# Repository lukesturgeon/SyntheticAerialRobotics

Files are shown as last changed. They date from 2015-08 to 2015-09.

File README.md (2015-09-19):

# SyntheticAerialRobotics #

Working repository for control software and Arduino code to choreograph a robotic performance. Using 4 stepper motors, drivers and software. This repository is started during a two month residency at [Laboratory](http://laboratoryspokane.com) Spokane and is a development of an original project [Choreographed Synthetic Temperaments in Aerial Robotics](http://lukesturgeon.co.uk/Choreographed-Synthetic-Temperaments-in-Aerial-Robotics).

---

## Arduino ##

#### AccelStepper_x4
A working sketch that allows serial communication to control and calibrate four stepper motors simultaniously. At it's core is the Calibrated_AccelStepper class which extends the awesome [AccelStepper library](http://www.airspayce.com/mikem/arduino/AccelStepper/) to include a calibration method using a limit switch to wind in and then unwind the cables.

##### Commands
- 1,2,3,4 : four long int to move each motor to the new length in MM
- s : sleep
- w : wake
- u : unlock
- l : lock
- ccw0 : 1 step counterclockwise for motor 0
- cw2 : 1 step clockwise for motor 2
- z1 : set current position to zero for motor 1
- c3 : start calibration process for motor 3
- ms : set max speed
- ma : set max acceleration
- ?l : get locked status
- ?s : get sleep status
- ?c : et calibration status (all four motors)
- ?mm : get length in MM (all four motors)

---

## Processing ##

#### SyntheticAerialRoboticsInterface
A working sketch to visualise and measure the position of the actor in 3D space. Using real-world measurements in CM to construct the box, all values afterwards will work at that scale.

#### single_stepper_controller
A working sketch that includes all basic interface elements necessary to interact with a single motor.

---

## Resources ##
- Datasheets for variable electronic components
- quadstepper.fzz : The circuit diagram and components created in Fritzing.
- powersupply.pdf : The power supply used for the installation 12V 5A
- motor-unit.ai : The illustrator file used to fabricate the acrylic sheets to assemble the four motor units. This file is to scale but some measurements are imprecise. File reflects the changes made manually to the current working acrylic sheets.
- installation-setup.ai : floorplan and dimensions for public installation at Laboratory Residency in Spokane, US.

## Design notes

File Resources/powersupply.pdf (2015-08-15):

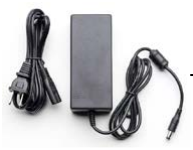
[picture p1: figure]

12V 5A switching power supply
—
It can supply 12V DC up to 5 Amps, running from 110V or 220V power (https://www.adafruit.com/products/352)

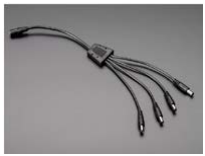
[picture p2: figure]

4-Way 2.1mm DC Barrel Jack Splitter
—
(https://www.adafruit.com/products/1352)

2.1mm female/mail barrel jack extension cable 1.5m —
The heavy 22 AWG wires can handle up to 5A. (https://www.adafruit.com/products/327)

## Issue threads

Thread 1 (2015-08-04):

unsynced position between oF and arduino

lukesturgeon, 2015-08-04:
this causes the motors to repostion and tare things apart.

currentposition in OF needs to be live and pulled from arduino directly.

lukesturgeon, 2015-08-13:
this has been fixed with a capacitor between RESET pin and GND. the arduino will not reset when multiple serial connections are made. so you can repeatedly connect without reseting the board. then query the board to get the current positions etc.

Closed 2015-08-13.

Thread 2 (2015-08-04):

tracking people close/far through glass windows

lukesturgeon, 2015-08-04:

lukesturgeon, 2015-08-04:
people tracking could be done with
– facetracking (faces)
– bodtracking (human)
– object tracking (red ball)
– Kinect?

https://github.com/hirotakaster/ofxOpenNI2

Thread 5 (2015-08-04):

recorded motion will NOT scale if the installation size changes

lukesturgeon, 2015-08-04:

lukesturgeon, 2015-09-02:
fixed with the current coordinate system automatically.

Closed 2015-09-02.

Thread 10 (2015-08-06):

motor rotates when uploading new arduino sketch

lukesturgeon, 2015-08-06:

lukesturgeon, 2015-08-08:
this could be fixed in the step wire was disabled between the arduino and driver during upload?

lukesturgeon, 2015-08-15:
fixed with latest merge. using accelstepper library has removed this effect

Closed 2015-08-15.

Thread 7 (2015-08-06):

motor shakes when arduino is connected and module is not in use

lukesturgeon, 2015-08-06:

lukesturgeon, 2015-08-08:
this could be fixed if all those pins were pulled LOW first. I think it's noise in the circuit.

lukesturgeon, 2015-08-14:
that's hasn't' occurred since upgrading to AccelStepper library

Closed 2015-08-14.

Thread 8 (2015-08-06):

arduino restarts when serial connects

lukesturgeon, 2015-08-06:

lukesturgeon, 2015-08-06:
fixed using a 100uf cap between RESET and GND pins. mounted on main module with a switch.

The switch will block autoreset when connecting via serial, but enable autoreset when uploading new sketches to the board.

Closed 2015-08-06.

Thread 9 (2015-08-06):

use interrupt in arduino to improve stepping performance

lukesturgeon, 2015-08-06:

lukesturgeon, 2015-08-13:
this has been implemented, but no improvement has been noticed yet.

lukesturgeon, 2015-08-15:
not necessary with accelstepper

Closed 2015-08-15.

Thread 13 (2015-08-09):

emergency stop button

lukesturgeon, 2015-08-09:
within the electronics, to disable the "step" pins and stop the motors from moving, as well as isSystemLocked variable.

http://kinesysusa.com/product/rigger

lukesturgeon, 2015-08-14:
same as bug #3

Closed 2015-08-14.

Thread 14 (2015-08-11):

arduino motor and steps get out of sync when changing quickly.

lukesturgeon, 2015-08-11:

lukesturgeon, 2015-08-13:
tested:
------------
- it’s 1:1 step now, not micro stepping
- there’s no acceleration, just a counter variable
- the int doesn’t exceed 3000’ish

research:
------------
- my motors are rated 0.33A
- A4988 driver IC is capable of supplying 2 A per coil, the chip by itself will overheat at lower currents
- should have appropriate decoupling capacitors close to the board
- should ramp up the speed in code, not fullstep from the beginning (http://electronics.stackexchange.com/questions/143731/why-do-we-need-a-ramp-for-stepper-motor)

next steps:
------------
- test at low speeds
- set the current limit on the drivers (should be  0.75A)
- implement acceleration and deceleration to apply ramping
- apply trapezoidal ramping (http://www.societyofrobots.com/member_tutorials/book/export/html/314)
- overheating driver IC, heatsink?
- upgrade drivers to Black Edition A4988 (https://www.pololu.com/product/2128)

lukesturgeon, 2015-08-15:
fixed with latest merge. using AccelStepper instead of basic step code.

Closed 2015-08-15.

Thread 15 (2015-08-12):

rotating motor with no power, sends power through driver.

lukesturgeon, 2015-08-12:
might need to add a diode to control the flow of electricity to avoid power running back through the circuitry.

lukesturgeon, 2015-08-15:
minor bug, not worth pursuing now.

Closed 2015-08-15.

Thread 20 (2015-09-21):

limit switches should be flipped to improve reliability of being triggered

lukesturgeon, 2015-09-21:

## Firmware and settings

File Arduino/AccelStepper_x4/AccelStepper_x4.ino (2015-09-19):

#include <AccelStepper.h>
#include "Calibrated_AccelStepper.h"

boolean isSystemLocked = true;
const int numMotors = 4;
const int sleepPin = A0;

// step,  dir,    sensor
// green, yellow, red
Calibrated_AccelStepper stepper[numMotors] {
  Calibrated_AccelStepper(3, 2, 4),
  Calibrated_AccelStepper(6, 5, 7),
  Calibrated_AccelStepper(9, 8, 10),
  Calibrated_AccelStepper(12, 11, 13)
};


void setup()
{
  // wake the arduino by default
  pinMode(sleepPin, OUTPUT);
  digitalWrite(sleepPin, HIGH);

  // initialise the motors
  for (int i = 0; i < numMotors; i++)
  {
    stepper[i].setMinSteps(0);
    stepper[i].setMaxSteps(11637);
    stepper[i].setMaxSpeed(200);
    stepper[i].setAcceleration(200);
  }

  Serial.begin(115200);
}

void loop()
{
  for (int i = 0; i < numMotors; i++)
  {
    if ( stepper[i].isCalibrating() )
    {
      stepper[i].runCalibration();
    }

    else if ( stepper[i].isFreeStepping() ) {
      stepper[i].runFreeStep();
    }

    else if (!isSystemLocked)
    {
      if ( !stepper[i].isSensorBlocked() )
      {
        stepper[i].run();
      }
      else
      {
        // A hard stop is used if the motor is blocked
        // Will set the target position to the current position
        // To stop movement when the motor is run again
        for (int j = 0; j < numMotors; j++)
        {
          stepper[j].setSpeed(0.0);
          stepper[j].moveTo( stepper[j].currentPosition() );
        }

        isSystemLocked = true;
        Serial.println("l=1");
        return;
      }
    }
  }
}

boolean isSleeping() {
  return (digitalRead(sleepPin) == LOW);
}

void wake() {
  digitalWrite(sleepPin, HIGH);
  Serial.println("s=0");
  delay(2); // allow a 2ms delay for the system to stabalize
}

void serialEvent()
{
  static char buffer[80];
  if (readline(Serial.read(), buffer, 80) > 0) {
    // Convert buffer to a string
    String str = String(buffer);

    // - - - - - - MOVE - - - - - - -

    if ( str.indexOf(',') > 0 ) {
      // assume its for numbers
      if (isSystemLocked) {
        Serial.println("l=1");
      }
      else {
        // we have received a command, so lets wake the system up
        if (isSleeping()) {
          wake();
        }

        //extract all values
        long a = atol( strtok(buffer, ",") );
        long b = atol( strtok(0, ",") );
        long c = atol( strtok(0, ",") );
        long d = atol( strtok(0, ",") );

        // update targets
        stepper[0].moveToMM( a );
        stepper[1].moveToMM( b );
        stepper[2].moveToMM( c );
        stepper[3].moveToMM( d );
      }
    }

    else if ( str.startsWith("ccw") ) {
      if (isSleeping()) {
        // wake the system up
        wake();
      }
      int index = str.substring(3).toInt();
      stepper[index].freeStep(-100);
    }

    else if ( str.startsWith("cw") ) {
      if (isSleeping()) {
        // wake the system up
        wake();
      }
      int index = str.substring(2).toInt();
      stepper[index].freeStep(100);
    }

    else if ( str.startsWith("c") ) {
      if (isSleeping()) {
        // wake the system up
        wake();
      }
      int index = str.substring(1).toInt();
      isSystemLocked = true;
      stepper[index].initCalibration();
      // send lock status
      Serial.println("l=1");
    }

    // - - - - - - CONFIG - - - - - - -

    else if ( str.startsWith("ms") ) {
      int newSpeed = str.substring(2).toInt();
      for (int i = 0; i < numMotors; i++) {
        stepper[i].setMaxSpeed( newSpeed );
      }
    }

    else if ( str.startsWith("ma") ) {
      int newAcceleration = str.substring(2).toInt();
      for (int i = 0; i < numMotors; i++) {
        stepper[i].setAcceleration( newAcceleration );
      }
    }

    // - - - - - - SLEEP - - - - - - -

    else if ( str.equals("s") ) {
      digitalWrite(sleepPin, LOW);
      Serial.println("s=1");
    }

    else if ( str.equals("w") ) {
      digitalWrite(sleepPin, HIGH);
      Serial.println("s=0");
    }

    // - - - - - - LOCK - - - - - - -

    else if ( str.equals("u") ) {
      isSystemLocked = false;
      Serial.println("l=0");
    }

    else if ( str.equals("l") ) {
      isSystemLocked = true;
      Serial.println("l=1");
    }

    else if ( str.startsWith("z") ) {
      int index = str.substring(1).toInt();
      stepper[index].setCurrentPosition(0);
    }

    // - - - - - - GET - - - - - - -

    else if ( str.equals("?l") ) {
      Serial.print("l=");
      Serial.println(isSystemLocked);
    }

    else if ( str.equals("?s") ) {
      Serial.print("s=");
      Serial.println(isSleeping());
      //Serial.println( digitalRead(sleepPin) );
    }

    else if ( str.equals("?c") ) {
      String responseStr = "c=";
      for (int i = 0; i < numMotors; i++)
      {
        responseStr += stepper[i].isCalibrated();
        if (i < numMotors - 1) {
          responseStr += ",";
        }
      }
      Serial.println(responseStr);
    }

    else if ( str.equals("?mm") ) {
      String responseStr = "mm=";
      for (int i = 0; i < numMotors; i++)
      {
        responseStr += stepper[i].currentPosition();
        if (i < numMotors - 1) {
          responseStr += ",";
        }
      }
      Serial.println(responseStr);
    }
  }
}

int readline(int readch, char *buffer, int len)
{
  static int pos = 0;
  int rpos;

  if (readch > 0) {
    switch (readch) {
      case '\n': // Return new-lines
        rpos = pos;
        pos = 0;  // Reset position index ready for next time
        return rpos;
      case '\r': // Ignore on CR
        break;
      default:
        if (pos < len - 1) {
          buffer[pos++] = readch;
          buffer[pos] = 0;
        }
    }
  }
  // No end of line has been found, so return -1.
  return -1;
}

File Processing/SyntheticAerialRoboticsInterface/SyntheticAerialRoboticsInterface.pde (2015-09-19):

import controlP5.*; //<>//

final float         WIDTH_CM = 325.50; // left to right (in cm)
final float         DEPTH_CM = 303.00; // front to back (in cm)
final float         HEIGHT_CM = 279.50; // top to bottom (in cm)
final int           NUM_MOTORS = 4; // controls the loops and settings
final long          SLEEP_AFTER_MILLIS = 1000*60*10; // seconds until we should sleep

float               scaleCM = 100.0; // default size to scale down to
float               worldRotationX = 0.0;
float               worldRotationY = 0.0;

ControlP5           cp5;
Println             console;
WarningSystem       system;
Motor3dSerial       serial;
Motor3d[]           motor;
Target3d            actorTarget;
Target3d            actorPosition;
float               easing = 0.1;
int                 maxSpeed = 1000;
int                 prev_maxSpeed = maxSpeed;
int                 maxAcceleration = 500;
int                 prev_maxAcceleration = maxAcceleration;

Table               recordData;
int                 recordTimer;
boolean             isRecording;
boolean             isPlaying;
int                 playbackPosition;

int                 updateTimer;
int                 lastChangedTimer;
int                 lastQueryTimer;

PFont               headingFont;
PFont               bodyFont;

void setup() {

  // to improve performance and run less maths calculations
  frameRate(30);

  // aesthetics
  size(1400, 800, P3D);
  smooth(8);
  headingFont = loadFont("fonts/AkzidenzGrotesk-Bold-24.vlw");
  bodyFont = loadFont("fonts/AkzidenzGrotesk-Roman-11.vlw");

  // setup the warning system to check the status of the installation
  // this is the main system that validates and alerts
  system = new WarningSystem();

  isRecording = false;
  recordData = new Table();
  recordData.addColumn("x");
  recordData.addColumn("y");
  recordData.addColumn("z");

  motor = new Motor3d[4];
  motor[0] = new Motor3d(-WIDTH_CM/2, -HEIGHT_CM/2, -DEPTH_CM/2);
  motor[0].setLabel("A");
  motor[1] = new Motor3d(WIDTH_CM/2, -HEIGHT_CM/2, -DEPTH_CM/2);
  motor[1].setLabel("B");
  motor[2] = new Motor3d(WIDTH_CM/2, -HEIGHT_CM/2, DEPTH_CM/2);
  motor[2].setLabel("C");
  motor[3] = new Motor3d(-WIDTH_CM/2, -HEIGHT_CM/2, DEPTH_CM/2);
  motor[3].setLabel("D");

  // start in center of floor
  actorTarget  = new Target3d(0, HEIGHT_CM/2, 0);
  actorPosition = actorTarget.get();

  // connect to arduino
  serial = new Motor3dSerial();
  system.arduinoConnected = serial.connect(this, "/dev/tty.usbmodem411", 115200);

  cp5_init();
}

void resetSleep() {
  lastChangedTimer = millis();
  cp5.getController("sleep").setValue(0);
}

void update() {

  // move the actor closer to the target
  float dx = actorTarget.x - actorPosition.x;
  float dy = actorTarget.y - actorPosition.y;
  float dz = actorTarget.z - actorPosition.z;
  actorPosition.x += dx * easing;
  actorPosition.y += dy * easing;
  actorPosition.z += dz * easing;

  // have the lengths changed?
  boolean hasChanged = false;
  for (int i = 0; i < NUM_MOTORS; i++) {
    motor[i].calculateLengthTo( actorPosition );
    if (motor[i].hasChanged()) {
      hasChanged = true;
    }
  }

  if (hasChanged) {
    if (!system.isLocked && system.isSendingData) {
      // this is it, send lengths to arduino
      // if the system is sleeping it will automatically wake
      serial.sendLengthMM(  
        motor[0].getLengthMM(), 
        motor[1].getLengthMM(), 
        motor[2].getLengthMM(), 
        motor[3].getLengthMM()  );

      resetSleep();
    }
  } else {
    // nothing is happening, should we sleep?
    if (!system.isSleeping && millis() - lastChangedTimer > SLEEP_AFTER_MILLIS) {
      // times up, so sleep
      serial.sendCommand( Motor3dSerial.SLEEP );
    } else if (!system.isSleeping) {
      // keep counting
      cp5.getController("sleep").setValue(millis() - lastChangedTimer);
    }
  }

  // are we recording
  if (isRecording && (millis()-recordTimer) > 125) {
    TableRow newData = recordData.addRow();
    newData.setFloat("x", actorTarget.x);
    newData.setFloat("y", actorTarget.y);
    newData.setFloat("z", actorTarget.z);
    recordTimer = millis();
  }

  // are we playing
  else if (isPlaying && (millis()-recordTimer) > 125) {
    // update the target position
    actorTarget.set( 
      recordData.getFloat(playbackPosition, "x"), 
      recordData.getFloat(playbackPosition, "y"), 
      recordData.getFloat(playbackPosition, "z")  ); 

    if (playbackPosition < recordData.getRowCount()-1) {
      playbackPosition++;
    } else {
      isPlaying = false;
    }

    recordTimer = millis();
  }
}

void draw() {

  // run the maths and calculations
  if (millis()-updateTimer > 100) {
    updateTimer = millis();
    if (system.arduinoConnected) {
      update();
    }
  }

  // run the occasional status query to arduino
  if (millis()-lastQueryTimer > 3000) {
    lastQueryTimer = millis();

    if (!system.motorAReady || !system.motorBReady || !system.motorCReady || !system.motorDReady) {
      serial.sendCommand(Motor3dSerial.GET_IS_CALIBRATED);
    } else {
      serial.sendCommand(Motor3dSerial.GET_LENGTH_MM);
    }
  }

  // redraw interface 
  background(#020320);

  pushMatrix();
  translate(width/2, (height/2), scaleCM);
  rotateX(worldRotationX);
  rotateY(worldRotationY);


  //draw frame
  noFill();
  stroke(#82A5C6);
  box(WIDTH_CM, HEIGHT_CM, DEPTH_CM);

  // draw floor
  for (int i = 0; i < 10; i++) {
    line(-WIDTH_CM/2, HEIGHT_CM/2, map(i, 0, 10, DEPTH_CM/2, -DEPTH_CM/2), 
      WIDTH_CM/2, HEIGHT_CM/2, map(i, 0, 10, DEPTH_CM/2, -DEPTH_CM/2));
    line(map(i, 0, 10, -WIDTH_CM/2, WIDTH_CM/2), HEIGHT_CM/2, -DEPTH_CM/2, 
      map(i, 0, 10, -WIDTH_CM/2, WIDTH_CM/2), HEIGHT_CM/2, DEPTH_CM/2);
  }

  // draw cables
  stroke(255);
  for (int i = 0; i < 4; i++) {
    line(motor[i].x, motor[i].y, motor[i].z, 
      actorPosition.x, actorPosition.y, actorPosition.z);
  }

  // save actorTarget for 2d rendering
  actorTarget.calculate2d();
  actorPosition.calculate2d();

  /*noStroke();
   
   // draw actorPosition
   pushMatrix();
   fill(255);
   translate(actorPosition.x, actorPosition.y, actorPosition.z);
   //sphere(20);
   popMatrix();*/

  // draw motors
  for (int i = 0; i < NUM_MOTORS; i++) {
    motor[i].calculate2d();
  }

  // draw the recorded motion?
  stroke(255, 255, 0);
  noFill();
  beginShape();
  for ( TableRow row : recordData.rows() ) {
    vertex( row.getFloat("x"), row.getFloat("y"), row.getFloat("z") );
  }
  endShape();

  //== end world translate and zoom ==//
  popMatrix();

  pushStyle();
  noFill();
  strokeWeight(3);
  stroke(255);
  ellipse(actorTarget.screenX, actorTarget.screenY, 15, 15);
  noStroke();
  fill(255);
  ellipse(actorPosition.screenX, actorPosition.screenY, 10, 10);
  popStyle();

  for (int i = 0; i < NUM_MOTORS; i++) {
    motor[i].draw2d();
  }

  system.draw();
}
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

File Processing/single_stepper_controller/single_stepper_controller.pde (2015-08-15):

import controlP5.*;
import processing.serial.*;

ControlP5 cp5;
Serial arduino;

boolean isSystemLocked = true;
int currentStep = 0;
int currentLength = 0;
int millisTimer;

void setup() {
  size(1024, 768);
  cp5 = new ControlP5(this);

  cp5.addFrameRate().setInterval(10).setPosition(17, height - 30);

  cp5.addToggle("lockToggle")
    .setBroadcast(false)
    .setLabel("Locked (l/u)")
    .setValue(isSystemLocked)
    .setPosition(width-300, 20)
    .setSize(28, 28)
    .setBroadcast(true);

  cp5.addButton("zero")
    .setBroadcast(false)
    .setLabel("Zero (z)")
    .setValue(0)
    .setPosition(width-300, 120)
    .setSize(280, 28)
    .setBroadcast(true);
  cp5.addButton("ccw")
    .setBroadcast(false)
    .setLabel("CCW (ccw)")
    .setValue(0)
    .setPosition(width-300, 150)
    .setSize(280, 28)
    .setBroadcast(true);
  cp5.addButton("cw")
    .setBroadcast(false)
    .setLabel("CW (cw)")
    .setValue(0)
    .setPosition(width-300, 180)
    .setSize(280, 28)
    .setBroadcast(true);

  cp5.addButton("get")
    .setBroadcast(false)
    .setLabel("GET ALL (?s?mm?c?l)")
    .setValue(0)
    .setPosition(width-300, 230)
    .setSize(280, 28)
    .setBroadcast(true);

  cp5.addButton("stepCCW")
    .setBroadcast(false)
    .setLabel("STEP -100")
    .setPosition(width-300, 280)
    .setSize(280, 28)
    .setBroadcast(true);
  cp5.addButton("stepCW")
    .setBroadcast(false)
    .setLabel("STEP +100")
    .setPosition(width-300, 310)
    .setSize(280, 28)
    .setBroadcast(true);

  cp5.addSlider("currentStep")
    .setBroadcast(false)
    .setLabel("Steps")
    .setRange(1800, 0)
    .setPosition(400, 400)
    .setSize(30, 200)
    .setLock(true);
    
  cp5.addToggle("calibrateToggle")
    .setBroadcast(false)
    .setLabel("Calibrate (c)")
    .setPosition(400, 640)
    .setSize(30, 30)
    .setBroadcast(true);

  //printArray(Serial.list());
  arduino = new Serial(this, "/dev/tty.usbmodem411", 115200);
  arduino.bufferUntil('\n');

  // get all the latest data
  //arduino.write("?c\n");
  //arduino.write("?l\n");
  //arduino.write("?s\n");
  //arduino.write("?mm\n");
}

void draw() {

  if (millis()-millisTimer > 500) {
    millisTimer = millis();

    if (!isSystemLocked) {
      //arduino.write("?s\n");
      //arduino.write("?mm\n");
    }
  }

  //==========================================
  background(0);

  // output the commands for reference
  fill(255);
  String commandStr = "COMMANDS";
  commandStr += "\n-----------------------";
  commandStr += "\nu = unlock";
  commandStr += "\nl = lock";
  commandStr += "\nc = calibrate";
  commandStr += "\nz = zero";
  commandStr += "\ncw = 1 step CW";
  commandStr += "\nccw = 1 step CCW";
  commandStr += "\n-----------------------";
  commandStr += "\ns = step";
  commandStr += "\nmm = move";
  commandStr += "\n-----------------------";
  commandStr += "\n?s = get currentStep";
  commandStr += "\n?mm = get currentLength";
  commandStr += "\n?c = get calibrated";
  commandStr += "\n?l = get locked";
  text(commandStr, 20, 30);

  text(currentStep, 200, 30);
  text(currentLength, 400, 30);

  // controlbackground
  fill(255, 20);
  rect(width-320, 0, 320, height);
}

void keyPressed() {
  if (keyCode == DOWN) {
    stepCW();
  }
  
  else if (keyCode == UP) {
    stepCCW();
  }
  
  else if (key == 'c') {
    Toggle t = (Toggle) cp5.getController("calibrateToggle");
    t.setValue( true );
  }
}

void serialEvent(Serial p) {
  String message = p.readString();
  message = trim(message);

  if ( message.substring(0, 3).equals("mm=") ) 
  {
    String mm = message.substring(3);
    currentLength = int( mm );
  } else if ( message.substring(0, 2).equals("s=") ) 
  {
    String s = message.substring(2);
    currentStep = int( s );
    cp5.getController("currentStep").setValue(currentStep);
  } else if ( message.substring(0, 2).equals("c=") ) 
  {
    String c = message.substring(2);
    println("calibration = " + c);
    Toggle t = (Toggle) cp5.getController("calibrateToggle");
    t.setBroadcast(false);
    t.setValue( c.equals("1") ? true : false );
    t.setBroadcast(true);
  } else if ( message.substring(0, 2).equals("l=") ) 
  {
    String l = message.substring(2);
    isSystemLocked = l.equals("1") ? true : false;
    Toggle t = (Toggle) cp5.getController("lockToggle");
    t.setBroadcast(false);
    t.setValue(isSystemLocked);
    t.setBroadcast(true);
  } else
  {
    println("> "+message);
  }
}

public void lockToggle(boolean theFlag) {
  if (isSystemLocked) {
    println("try to unlock");
    arduino.write("u\n");
  } else {
    println("try to lock");
    arduino.write("l\n");
  }
  isSystemLocked = theFlag;
}

public void calibrateToggle(boolean theFlag) {
  if (theFlag) {
    println("run calibration");
    arduino.write("c\n");
  }
}

public void zero(int theValue) {
  println("zero the values");
  arduino.write("z\n");
}

public void cw(int theValue) {
  println("step once cw");
  arduino.write("cw\n");
}

public void ccw(int theValue) {
  println("step once ccw");
  arduino.write("ccw\n");
}

public void get(int theValue) {
  arduino.write("?c\n");
  arduino.write("?l\n");
  arduino.write("?s\n");
  arduino.write("?mm\n");
}

public void stepCW() {
  if (!isSystemLocked) {
    arduino.write("s" + (currentStep+=100) + "\n");
  } else {
    println("system locked");
  }
}

public void stepCCW() {
  if (!isSystemLocked) {
    arduino.write("s" + (currentStep-=100) + "\n");
  } else {
    println("system locked");
  }
}

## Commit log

2015-08-08 working SingleStepper.h class for Arduino
    includes detailed API / commands that can be sent over serial to
    control a single motor.
2015-08-08 commit of a functioning UI for the single_stepper_module Arduino sketch
    there is still missing functionality and controls in this interface.
    but it connects.
2015-08-12 replaced millis() with interrupt timer
2015-08-15 replaced old motor code with AccelStepper library
    using acceleration and deceleration to avoid missing steps when moving
    the motor. also appears to fix bug #10 (motor moves when uploading
    sketch).
    [Calibrated_AccelStepper.h]
2015-08-15 added component datasheets and start of motor unit design files
    [quadstepper.fzz]
2015-08-15 replaced openFrameworks sketch with Processing sketch
    [single_stepper_controller.pde]
2015-08-20 added working version of interface. x4 motors plus lengths
2015-08-20 added profile view/design of motor unit to measure screw lengths
2015-08-27 updated design file to fit M3 screws and holes for sensor cables.
2015-09-02 adding support for x4 motors and sync maths
    a working interface that controls the motors via arduino.
2015-09-03 building sync controls between arduino rig and processing sketch
    lock, unlock, cw, cow, zero, calibrate are now all working.
2015-09-09 expanded M3 screw holes so the motor can slide horizontally
    this allows the chain to be tightened by adjusting the position of the
    motor manually.
2015-09-10 removed test sketch because it's a fraction of the correct features
    [Calibrated_AccelStepper.h]
2015-09-12 added more commands support for arduino and recored wires
    [installation-setup.fzz]
2015-09-12 added warning system. [untested sleep feature].
    step-by-step status check until the system should work. to avoid errors.
    [Motor3D.pde, Serial3D.pde, SyntheticAerialRoboticsInterface.pde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]
2015-09-15 added sleep feature to disable motors after specific time
    send the sleep command and the arduino sends the result back.
    Introduced Motor3dController class and Target3d class to manage 3d
    maths.
2015-09-16 added freestepping feature to motors, to nudge 100steps C/CW
    this doesn’t replace stepCW and stepCCW but those 1step pieces are not
    implemented in the arduino code.
    [AccelStepper_x4.ino, Calibrated_AccelStepper.h]
2015-09-16 merged all design and pdfs in to Resources folder
    [installation-setup.fzz, quadstepper.fzz]
2015-09-16 calibrated for gallery space with sleep mode enabled
    set width, height in cm.
    sleep mode working
    some interface improvements to reduce controls
2015-09-19 slow default speed for motors. set max steps. configure for gallery
    fixed bug with calibration
    set size for gallery space
    [AccelStepper_x4.ino, Calibrated_AccelStepper.h, Motor3D.pde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]
